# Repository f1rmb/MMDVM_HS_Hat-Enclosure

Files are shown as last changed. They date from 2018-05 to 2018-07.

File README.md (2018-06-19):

# MMDVM_HS_Hat-Enclosure
Enclosures for MMDVM_HS hats (various board revisions)

Based on the enclosure shape from *Toufik*, **F0DEI**, here are some personnal variations, built from scratch.

**FreeCad** (https://www.freecadweb.org/) files are available (not for all variations, since the only differences are antenna and screen cutouts).

I'm using the daily snapshots (https://launchpad.net/~freecad-maintainers/+archive/ubuntu/freecad-daily), so using the latest stable version may not works.

All STL files are also provided, just open them in your favorite slicer, then 3D print'em.

__WARNING__
You should use supports for top and bottom parts.

 <br><br>
## Full height enclosures
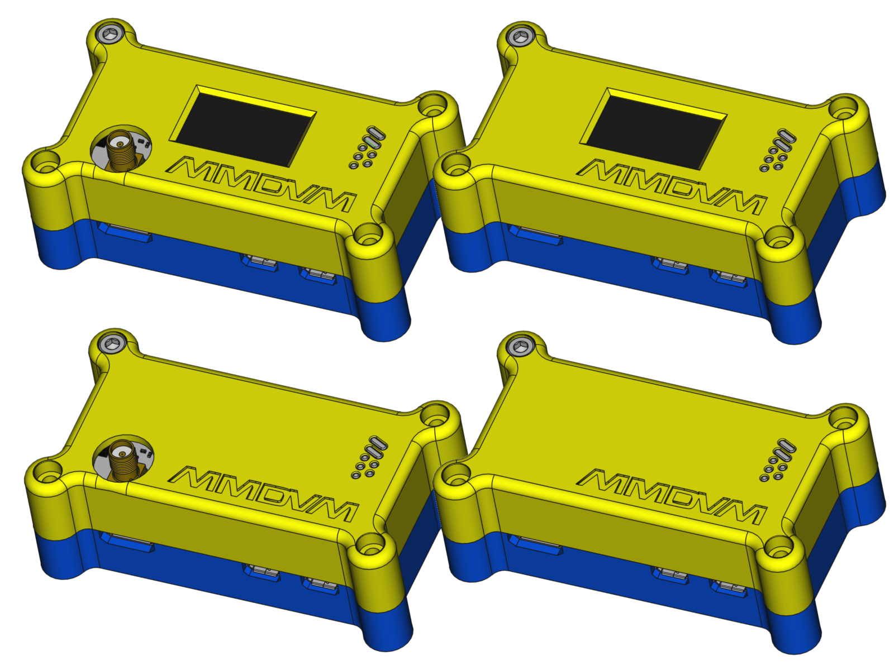
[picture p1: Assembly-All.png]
FULL


 <br><br>
## Slim enclosures
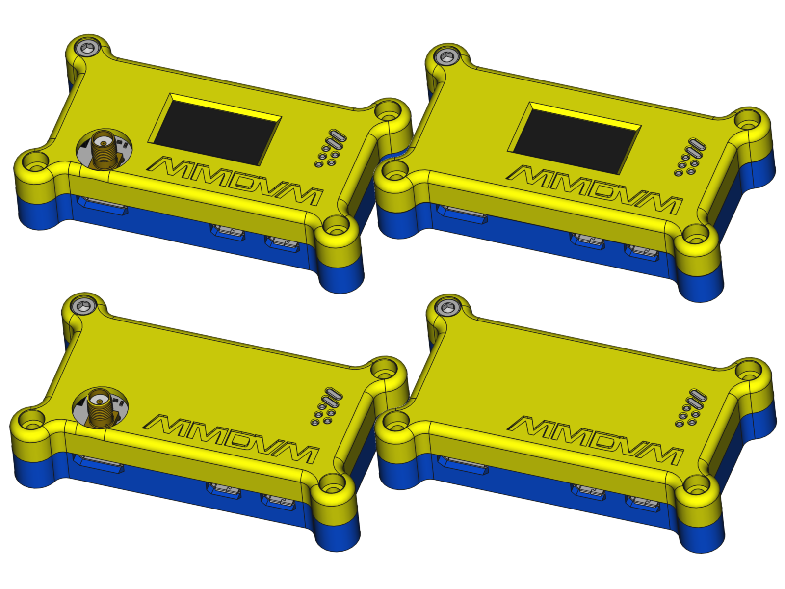
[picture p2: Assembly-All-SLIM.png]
SLIM


 <br><br>
## All 3 major PCB versions are supported:

* 1.2
  * Also known as *chinese* jumbospot
* 1.6
  * latest official version from DB9MAT and DF2ET (https://github.com/mathisschmieder/MMDVM_HS_Hat)
* 1.7
  * my slightly modified version, made out of a 1.6 fork (https://github.com/f1rmb/MMDVM_HS_Hat)

 <br><br>
## Parts needed for assemblies:

 __For full height assembly__

 Qty | Part
 ----|------
 1 | bottom assembly (file: MMDVM_HS_Bottom.stl) 
 1 | top cover (choose between blind, antenna and screen, in PCB-\<version\> directory, accordingly), non SLIM.
 4 | M2 1.2mm 3D printed washers (file: Parts/Washer-M2x1.2mm.stl)
 4 | M2 11.35mm 3D printed spacers (file: Parts/Spacer-M2x11.35mm.stl)
 4 | M2x20mm socket headed CHC screws
 4 | M2 hex nuts
 4 | M3x20mm socket headed CHC screws
 4 | M3 hex nuts
 1 | light diffuser (optional) (file: Parts/Light-Diffuser-PCB-v1.7.stl)

 <br><br>
 __For SLIM assembly__

 Qty | Part
 ----|------
 1 | bottom assembly (file: MMDVM_HS_Bottom-SLIM.stl) 
 1 | top cover (choose between blind, antenna and screen, in PCB-\<version\> directory, accordingly), -SLIM.
 4 | M2 1.2mm 3D printed washers (file: Parts/Washer-M2x1.2mm.stl)
 4 | M2 5mm 3D printed spacers (file: Parts/Spacer-M2x5mm.stl)
 4 | M2x12mm socket headed CHC screws
 4 | M2 hex nuts
 4 | M3x12mm socket headed CHC screws
 4 | M3 hex nuts
 1 | light diffuser (optional) (file: Parts/Light-Diffuser-PCB-v1.7.stl)
 
 ***Some specific assembly informations will be added later about this SLIM version.***

 <br><br>
## License
This project is released under the Creative Commons Attribution-NonCommercial-ShareAlike 4.0 (CC-BY-NC-SA 4.0, https://creativecommons.org/licenses/by-nc-sa/4.0/) license. You may edit and share it as you like, as long as credit is given and the license is not changed. You can build as many enclosures for you and your friends as you like and you can even sell it to them to cover your costs, **however it is strictly forbidden to turn this into a commercial product! You are not allowed to build and sell these enclosures for profit!. WE ARE HAM RADIO, keep that in mind!**

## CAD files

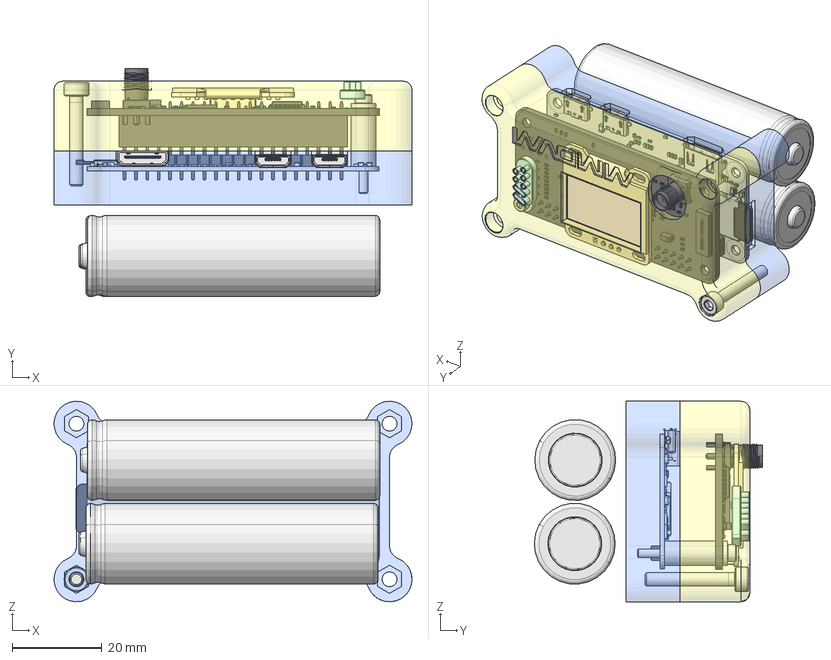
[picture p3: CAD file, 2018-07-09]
PCB-v1.7/Assembly-with-batteries.fcstd
79.6 x 50.8 x 44.6 mm
myzero_PCB_01
myzero_Components_01
OLED_27x27_STEP1_01
PinHeader_2x20_P2_54mm_Vertical_step1_01
MMDVM_HS_Bottom_01
Micro_SD_Card_STEP1_01
M3x20-Screw
M2x20-Screw
Spacer_M2x11_35mm_01
Washer_M2x1mm_01
mmdvm_hs_hat_01
Light_Diffuser_PCB_v1_7_01
MMDVM_HS_Top_PCB_v1_7_01

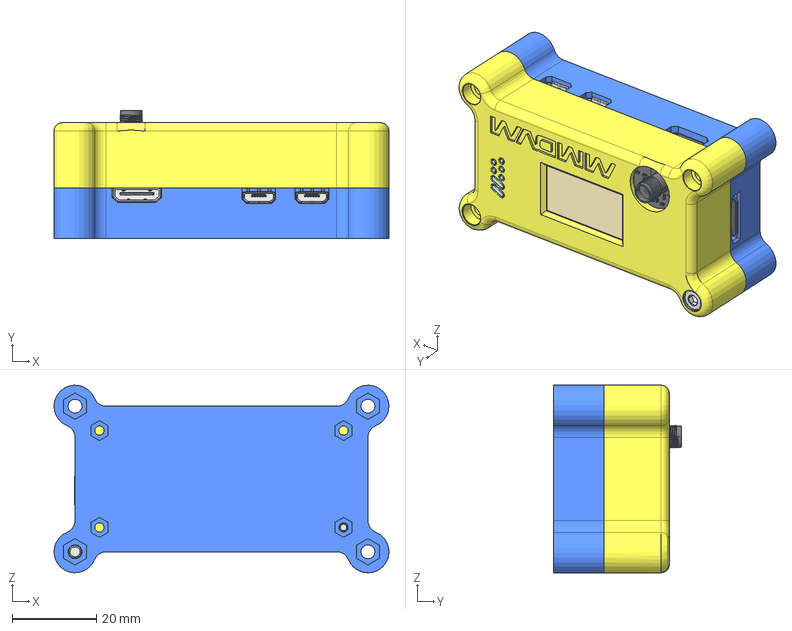
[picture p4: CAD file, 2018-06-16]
PCB-v1.7/Assembly.fcstd
79.6 x 30.4 x 44.6 mm
myzero_PCB_01
myzero_Components_01
OLED_27x27_STEP1_01
PinHeader_2x20_P2_54mm_Vertical_step1_01
MMDVM_HS_Bottom_01
Micro_SD_Card_STEP1_01
M3x20-Screw
M2x20-Screw
Spacer_M2x11_35mm_01
Washer_M2x1mm_01
mmdvm_hs_hat_01
Light_Diffuser_PCB_v1_7_01
MMDVM_HS_Top_PCB_v1_7_01

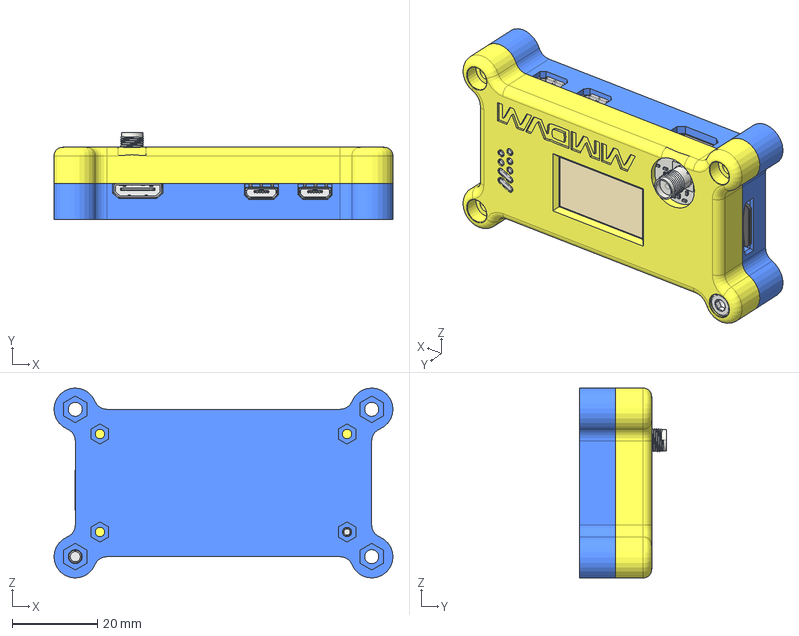
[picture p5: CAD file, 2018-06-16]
PCB-v1.7/Assembly-SLIM.fcstd
79.6 x 20.5 x 44.6 mm
myzero_PCB_01
myzero_Components_01
MMDVM_HS_Bottom_SLIM_01
PinHeader_2x20_P2_54mm_Vertical_step1_01
mmdvm_hs_hat_NO_PINSOCKET_01
Spacer_M2x5mm_01
Light_Diffuser_PCB_v1_7_01
M3x12-Screw
M2x12-Screw
Washer_M2x1mm_01
Micro_SD_Card_STEP1_01
MMDVM_HS_Top_PCB_v1_7_SLIM_01
OLED_27x27_STEP1_01

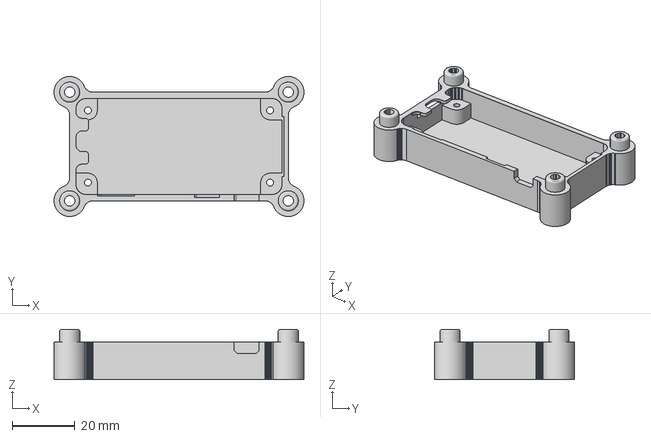
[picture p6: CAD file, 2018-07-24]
MMDVM_HS_Bottom-Single-USB.fcstd
79.6 x 44.6 x 16.0 mm
Pad005 (Meshed)

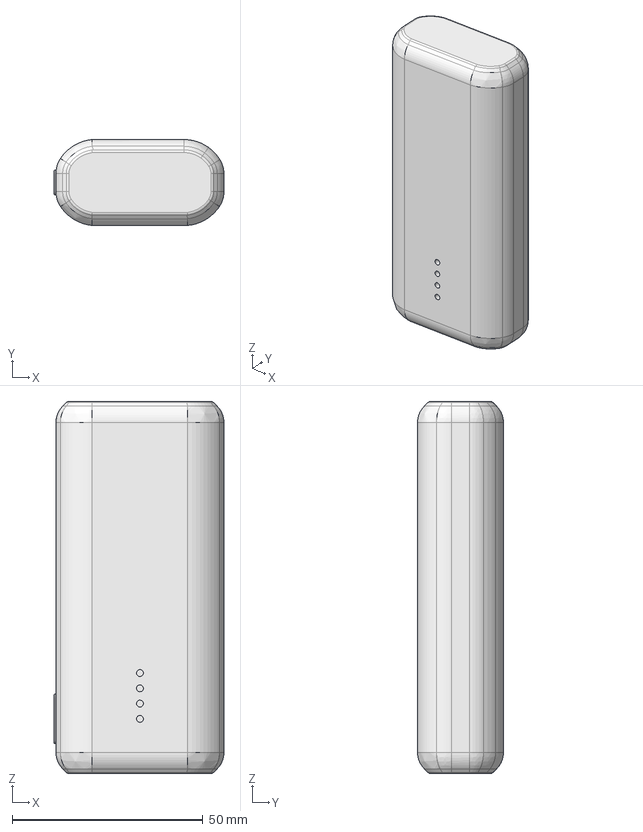
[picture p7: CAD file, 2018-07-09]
Parts/anker.fcstd
44.5 x 22.5 x 97.4 mm

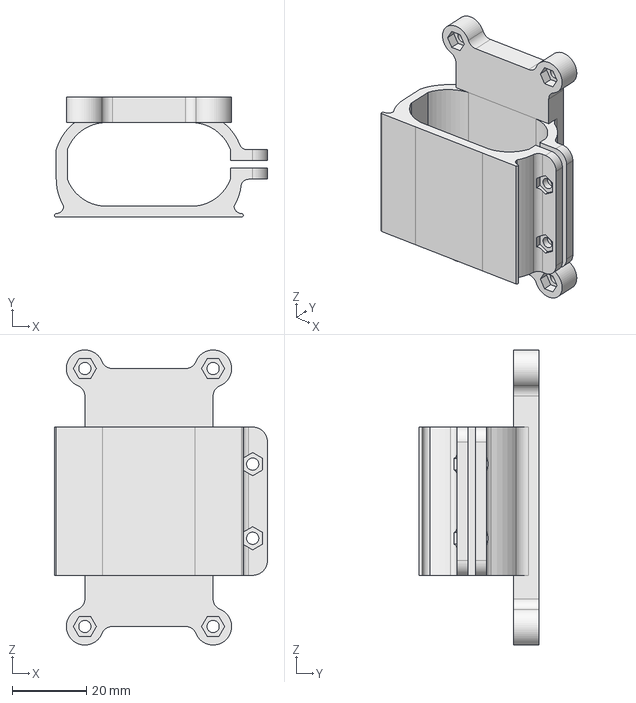
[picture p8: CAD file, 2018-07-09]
PowerBank_Support/anker-astro-support.fcstd
57.5 x 32.5 x 79.6 mm

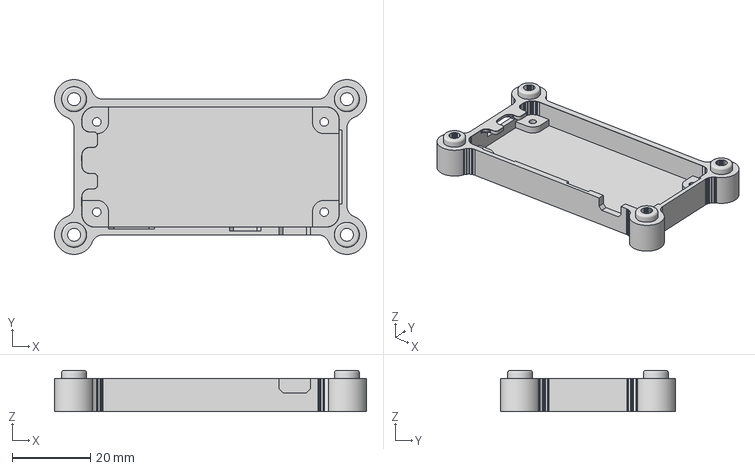
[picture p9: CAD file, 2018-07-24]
MMDVM_HS_Bottom-SLIM-Single-USB.fcstd
79.6 x 44.6 x 10.5 mm
Pad005 (Meshed)

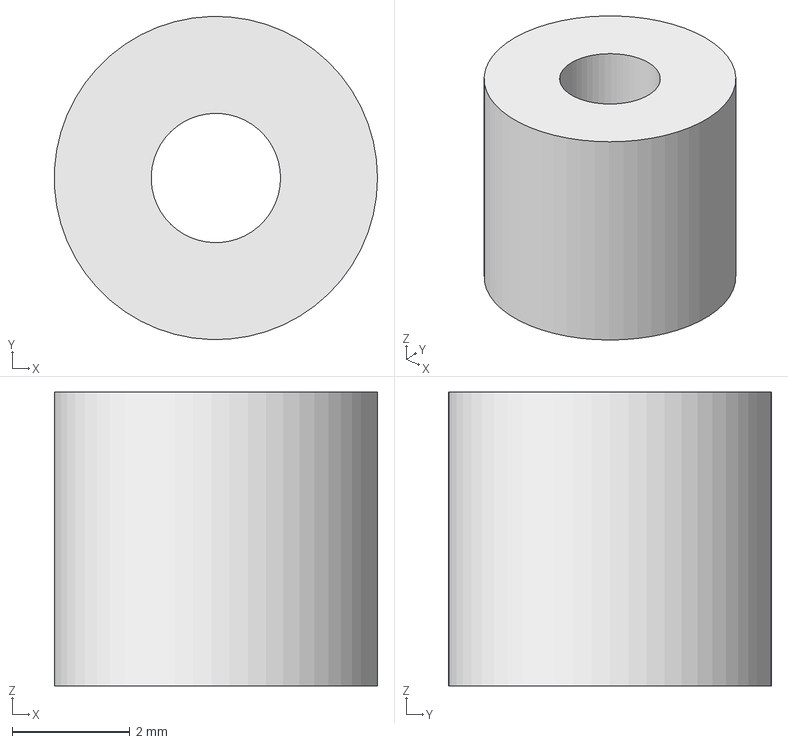
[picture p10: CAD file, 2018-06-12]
Parts/Spacer_M2x5mm.fcstd
5.50 x 5.50 x 5.00 mm

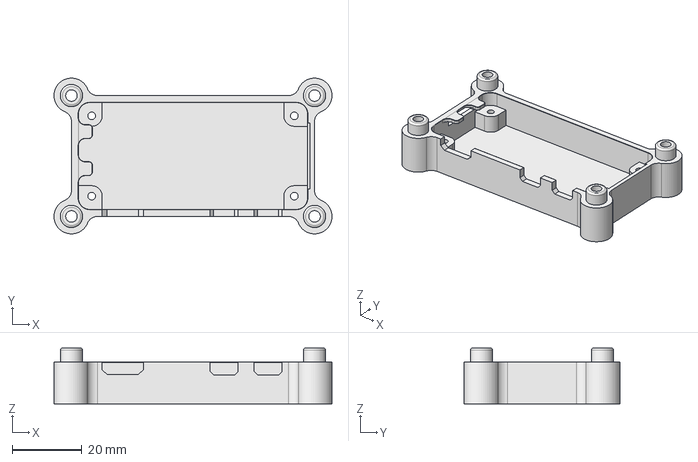
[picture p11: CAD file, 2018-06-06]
MMDVM_HS_Bottom.fcstd
79.6 x 44.6 x 16.0 mm

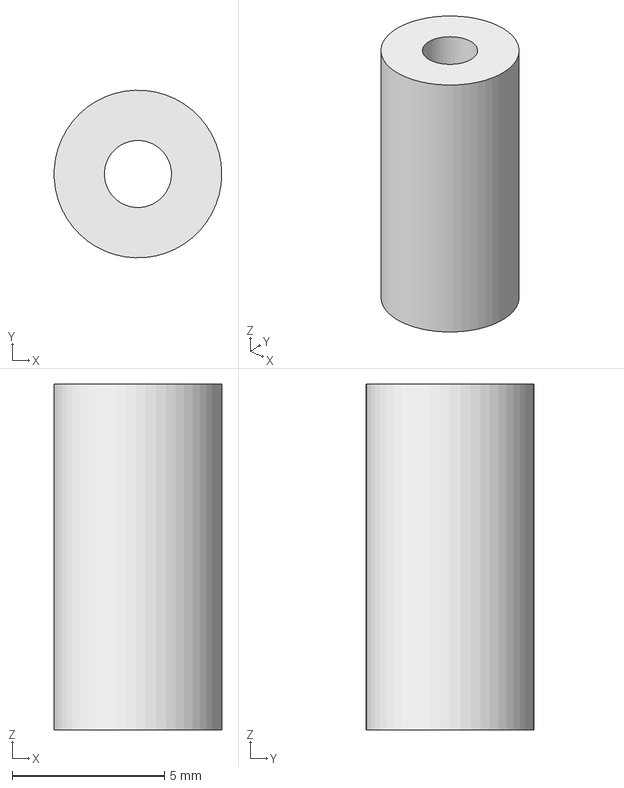
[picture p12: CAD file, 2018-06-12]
Parts/Spacer_M2x11.35mm.fcstd
5.49 x 5.50 x 11.3 mm

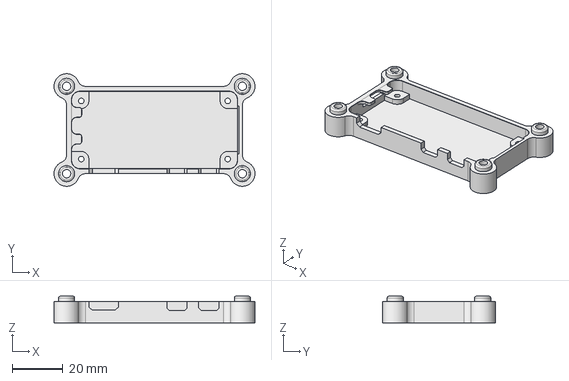
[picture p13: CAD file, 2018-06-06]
MMDVM_HS_Bottom-SLIM.fcstd
79.6 x 44.6 x 10.5 mm

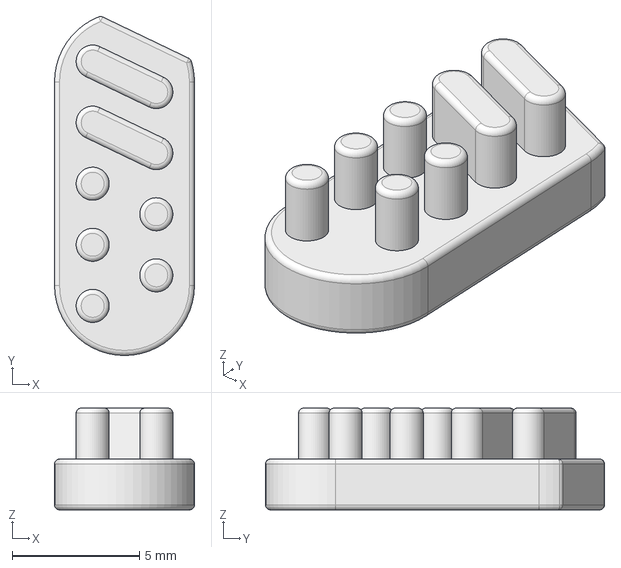
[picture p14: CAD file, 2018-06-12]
Parts/Light_Diffuser-PCB-v1.7.fcstd
5.50 x 13.3 x 4.00 mm

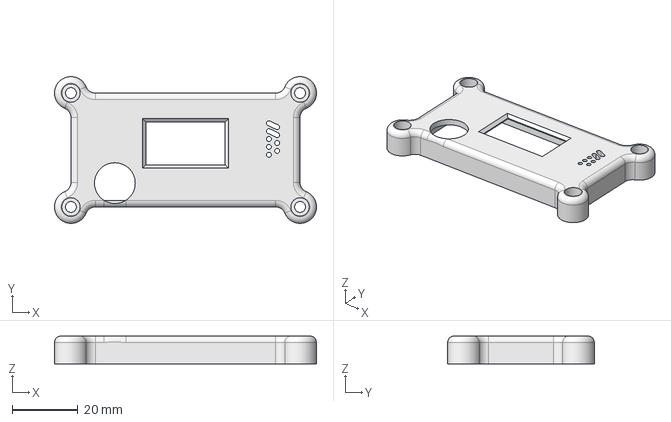
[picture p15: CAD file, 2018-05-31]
PCB-v1.7/MMDVM_HS_Top-Antenna-PCB-v1.7-SLIM.fcstd
79.6 x 44.6 x 8.50 mm

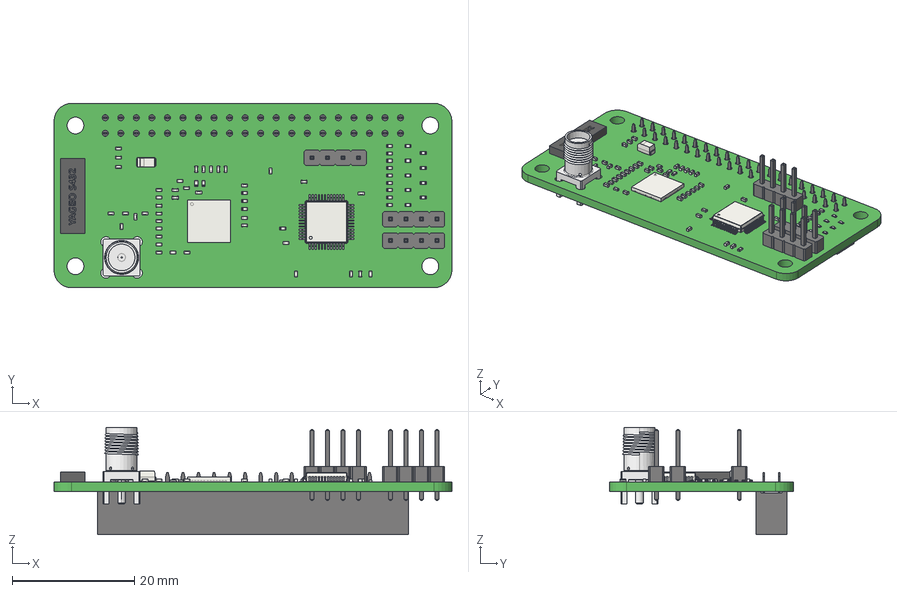
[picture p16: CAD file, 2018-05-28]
PCB-v1.7/mmdvm_hs_hat.FCStd
65.1 x 30.2 x 17.5 mm
Pcb
C_0402_1005Metric_
C_0402_1005Metric_001
C_0402_1005Metric_002
C_0402_1005Metric_003
C_0402_1005Metric_004
C_0402_1005Metric_005
C_0402_1005Metric_006
C_0402_1005Metric_007
C_0402_1005Metric_008
C_0402_1005Metric_009
C_0402_1005Metric_010
C_0402_1005Metric_011
C_0402_1005Metric_012
C_0402_1005Metric_013
C_0402_1005Metric_014
C_0402_1005Metric_015
C_0402_1005Metric_016
C_0402_1005Metric_017
C_0402_1005Metric_018
C_0402_1005Metric_019
C_0402_1005Metric_020
C_0402_1005Metric_021
C_0402_1005Metric_022
C_0402_1005Metric_023
C_0402_1005Metric_024
C_0402_1005Metric_025
C_0402_1005Metric_026
C_0402_1005Metric_027
C_0402_1005Metric_028
C_0402_1005Metric_029
CP_EIA_3216_18_Kemet_A_
PinHeader_1x04_P254mm_Vertical_
PinHeader_1x04_P254mm_Vertical_001
PinHeader_1x04_P254mm_Vertical_002
L_0402_1005Metric_
L_0402_1005Metric_001
L_0402_1005Metric_002
L_0402_1005Metric_003
L_0402_1005Metric_004
L_0402_1005Metric_005
APG1005_
APG1005_001
APG1005_002
APG1005_003
APG1005_004
APG1005_005
APG1005_006
APG1005_007
APG1005_008
R_0402_1005Metric_
R_0402_1005Metric_001
R_0402_1005Metric_002
R_0402_1005Metric_003
R_0402_1005Metric_004
R_0402_1005Metric_005
R_0402_1005Metric_006
R_0402_1005Metric_007
R_0402_1005Metric_008
R_0402_1005Metric_009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

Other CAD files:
PCB-v1.7/MMDVM_HS_Top-Antenna-PCB-v1.7.fcstd
Parts/OLED_27x27.STEP
Parts/PinHeader_1x04_P2.54mm_Vertical.step
Parts/PinHeader_2x20_P2.54mm_Vertical.step
MMDVM_HS_Bottom.stl
PCB-v1.2/Assembly-NEW-LEDs.fcstd
PCB-v1.2/Assembly.fcstd
PCB-v1.2/MMDVM_HS_Top-PCB-v1.2.fcstd
PCB-v1.2/MMDVM_HS_Top-Screen-PCB-v1.2.fcstd
PCB-v1.2/mmdvm_hs_hat.FCStd
PCB-v1.6/Assembly-SLIM.fcstd
PCB-v1.6/Assembly.fcstd
Parts/Light-Diffuser-PCB-v1.2.stl
Parts/Light_Diffuser-PCB-v1.2.fcstd
Parts/Micro SD Card.STEP
Parts/Micro SD Card.stl
Parts/Spacer-M2x11.35mm.stl
Parts/Spacer-M2x5mm.stl
Parts/Washer-M2x1.2mm.stl
Parts/Washer-M2x1mm.stl
Parts/Washer_M2x1.2mm.fcstd
Parts/Washer_M2x1mm.fcstd

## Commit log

2018-05-26 Import parts, PCB-v1.2 is done.
    [Assembly.fcstd, MMDVM_HS_Bottom-HACK.fcstd, MMDVM_HS_Bottom.fcstd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]
2018-05-26 Update the assembly, add F1RPC enclosure 3D image.
    [Assembly.fcstd]
2018-05-28 Add light diffuser.
    [Assembly.fcstd, Light-Diffuser.stl]
2018-05-28 Move external dependencies into repo.
    [Assembly.fcstd, Light-Diffuser-PCB-v1.2.stl, Light-Diffuser.stl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]
2018-05-28 Import PCB 1.6 and 1.7.
    [mmdvm_hs_hat.FCStd]
2018-05-28 Starts cover mods for PCB-v1.7.
    [Assembly.fcstd, MMDVM_HS_Top-Antenna-PCB-v1.7.fcstd]
2018-05-30 Update LEDs cutting.
    [MMDVM_HS_Top-Antenna-PCB-v1.7.fcstd]
2018-05-30 Light diffuser change (WiP).
    [Assembly.fcstd, MMDVM_HS_Top-Antenna-PCB-v1.7.fcstd]
2018-05-31 Create light diffuser for PCB v1.7.
    [Assembly.fcstd, Light_Diffuser-PCB-v1.7.fcstd, MMDVM_HS_Top-Antenna-PCB-v1.7.fcstd]
2018-05-31 Fix screen clearance. Add SLIM version.
    [Assembly-SLIM.fcstd, Light_Diffuser-PCB-v1.7.fcstd, MMDVM_HS_Bottom-SLIM.fcstd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]
2018-06-01 Add SDCard anti-urn. Update assemblies.
    [Assembly-SLIM.fcstd, Assembly.fcstd, MMDVM_HS_Bottom-SLIM.fcstd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]
2018-06-06 Latest fine adjustments of version for PCB v1.7, slim and full size versions.
    [Assembly-SLIM.fcstd, MMDVM_HS_Bottom-SLIM.fcstd, MMDVM_HS_Bottom.fcstd]
2018-06-06 Update assemblies.
    [Assembly-SLIM.fcstd, Assembly.fcstd, MMDVM_HS_Bottom-SLIM.fcstd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]
2018-06-12 Parts cleanup, redo STL files.
    [Light-Diffuser-PCB-v1.2.stl, Light_Diffuser-PCB-v1.2.fcstd, Light_Diffuser-PCB-v1.7.fcstd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]
2018-06-12 Add NEW-LEDs diffuser style cover. Rename Top cover fi;es. Update Assemblies.
    [Assembly-NEW-LEDs.fcstd, Assembly.fcstd, MMDVM_HS_Top-Antenna-PCB-v1.2.fcstd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]
2018-06-12 Add variations of STL files for top covers (old LEDs).
    [Assembly-SLIM.fcstd, Assembly.fcstd, MMDVM_HS_Top-Screen-PCB-v1.2.fcstd]
2018-06-12 Rename STL without antenna and screen holes as blind.
    [MMDVM_HS_Top-PCB-v1.2.fcstd]
2018-06-12 Add variations of STL files for top covers (new LEDs). Add forgotten STL file for old LEDs.
2018-06-12 Rename Top covers. Update assemblies.
    [Assembly-SLIM.fcstd, Assembly.fcstd]
2018-06-12 Add variations of STL files for full size top cover.
2018-06-12 Add variations of STL files for slim size top cover.
2018-06-13 Import covers and stuff for PCB-v1.6 (WiP).
    [Assembly-SLIM.fcstd, Assembly.fcstd]
2018-06-13 Reimport PCB from KiCad (something was strange with LEDs positions. Update the assemblies.
    [Assembly-SLIM.fcstd, Assembly.fcstd]
2018-06-14 Fix duplicate constraints in both drawings. Import and update STL files variations for full size top covers.
2018-06-15 Add variations of STL files for slim size top covers.
2018-06-16 Import assemblies images.
2018-06-16 Fix order mess.
    [Assembly-SLIM.fcstd, Assembly.fcstd]
2018-06-19 Fix screws size...
2018-07-09 Add anker powerbank
    [anker.fcstd]
2018-07-09 Add support for anker powerbank.
    [anker-astro-support.fcstd]
2018-07-09 Add SLIM assembly with powerbank support.
    [Assembly-with-batteries.fcstd]
2018-07-24 Add bottom parts with only the power USB port available.
    [MMDVM_HS_Bottom-SLIM-Single-USB.fcstd, MMDVM_HS_Bottom-Single-USB.fcstd]
